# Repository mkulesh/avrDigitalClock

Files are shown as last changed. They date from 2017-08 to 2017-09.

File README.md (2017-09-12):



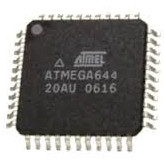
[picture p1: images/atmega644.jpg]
#  "A digital clock based on ATmega644 MCU"

This repository provides hardware layout and firmware for a digital clock based on ATmega644 MCU
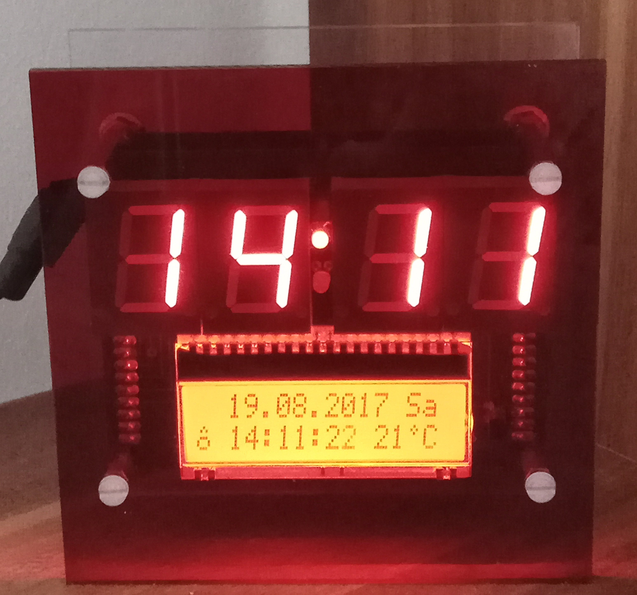
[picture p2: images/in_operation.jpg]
In operation


## Hardware design
This clock consist of two boards:
- the first display board contains four 0.8 inch. single digit numerical displays and one 2x16 chars LCD-display.
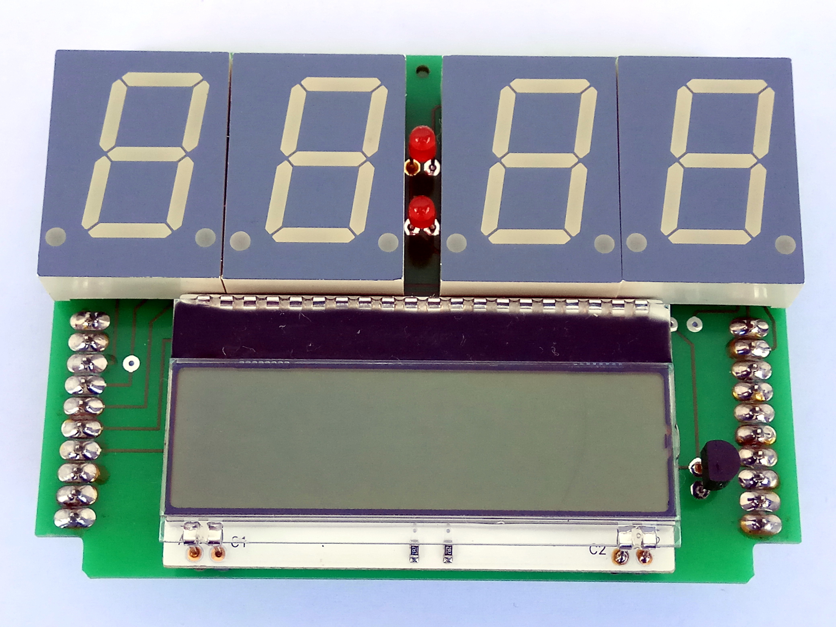
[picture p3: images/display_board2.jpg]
Display board


- the second board contains ATmega644 MCU with necessary periphery: voltage regulator, light sensor, temperature sensor, buttons, programming connector, 32.7680kHz crystal, DCF77 receiver with ferrite core.
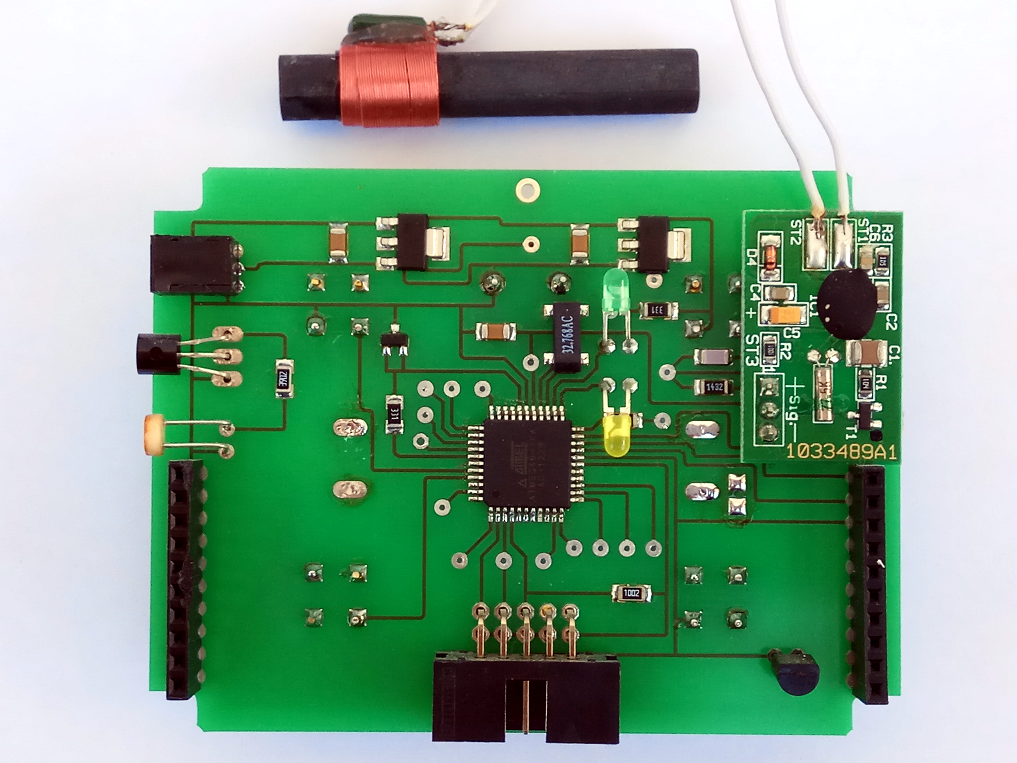
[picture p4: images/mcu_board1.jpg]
Mcu board


PCB are developed in Eagle CAD (see directory pcb):
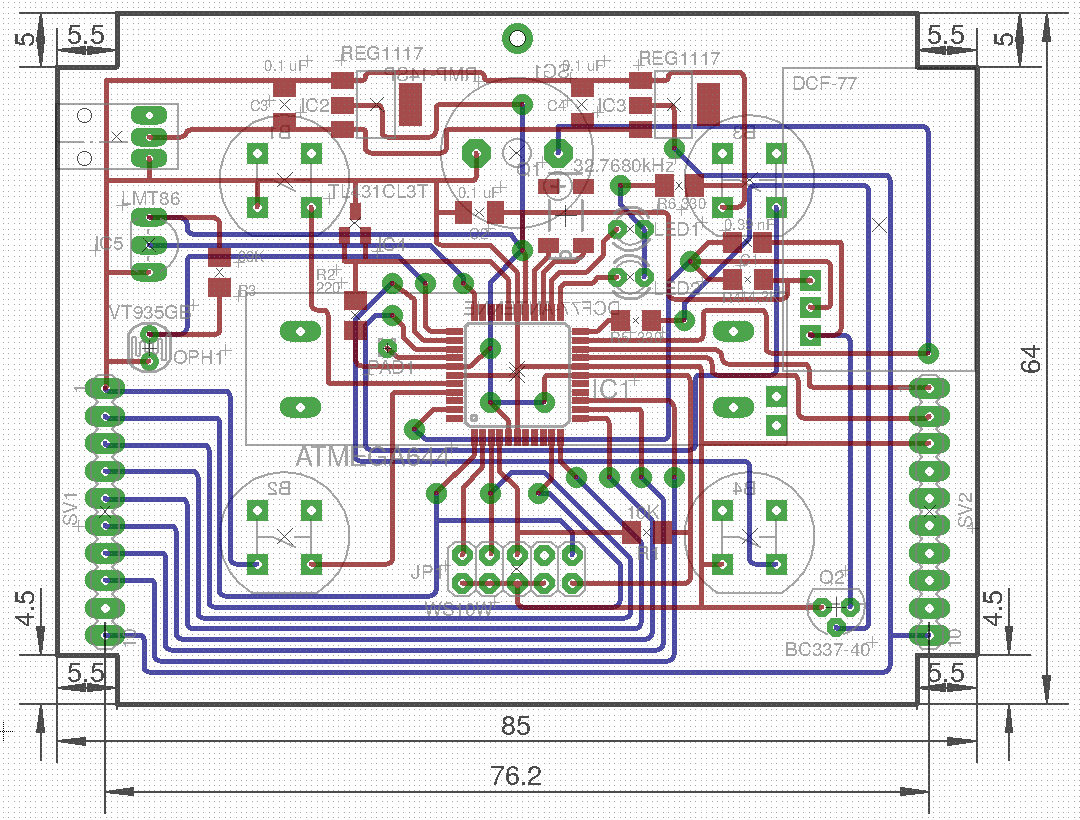
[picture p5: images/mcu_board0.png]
Mcu board layout

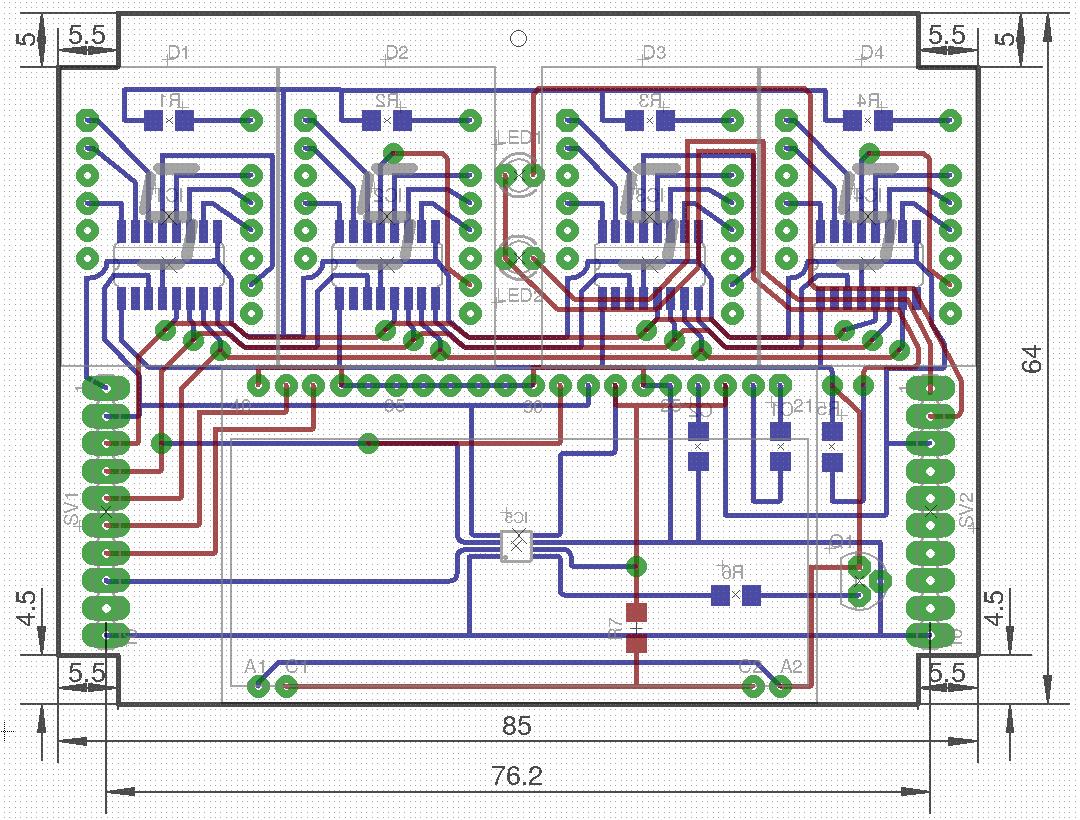
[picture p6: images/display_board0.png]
Display board layout


## Firmware
The firmware is written in C++ in Atmel Studio 6.0 (see directory src). The main idea here is to collect low-level routines in an object-oriented library and develop the main logic of the application using objects that implements different hardware elements.

## List of components
- DC connector: 1x DC-8N
- voltage regulators: 2x LD1117S33CTR
- temperature sensor: 1x LMT86LP
- voltage reference: 1x TL431CL3T
- 32.7680kHz crystal: 1x EuroQuartz PH32768X
- DCF77 receiver: 1x ELV Elektronik DCF-2 with ferrite core
- LED 3mm: 4x
- light sensor: 1v VT935G-B
- MCU ATMEGA644PA-AU TQFP-44
- transistors: 1xBC337-40, 1x J105
- piezo buzzer: 1x RMP-14SP
- buttons: 4x D6X
- shift register: 4x SN74HC595DR
- digital/analog converter: 1x MCP4901
- 7-segment display: 4x SC08-11SRWA
- LCD-display: 1x DOG-M162 with back-light (i.e EA LED55X31-R)

## There are some known problems in this project
- DCF-2 works really bad (instable signal): ether ferrite core or software problem
- Resting in Eagle design rules is invalid
- Wrong position of the DC connector: it shall be placed on bottom instaead of top of board
- voltage of 7-segment display and LCD back-light is regulated using MCP4901 and J105: regulation interal is too short

## License

This software is published under the *GNU General Public License, Version 3*

Copyright (C) 2014-2017 Mikhail Kulesh

This program is free software: you can redistribute it and/or modify it under the terms of the GNU General Public License as published by the Free Software Foundation, either version 3 of the License, or (at your option) any later version.

This program is distributed in the hope that it will be useful, but WITHOUT ANY WARRANTY; without even the implied warranty of MERCHANTABILITY or FITNESS FOR A PARTICULAR PURPOSE.  See the GNU General Public License for more details. You should have received a copy of the GNU General Public License along with this program.

If not, see [www.gnu.org/licenses](http://www.gnu.org/licenses).

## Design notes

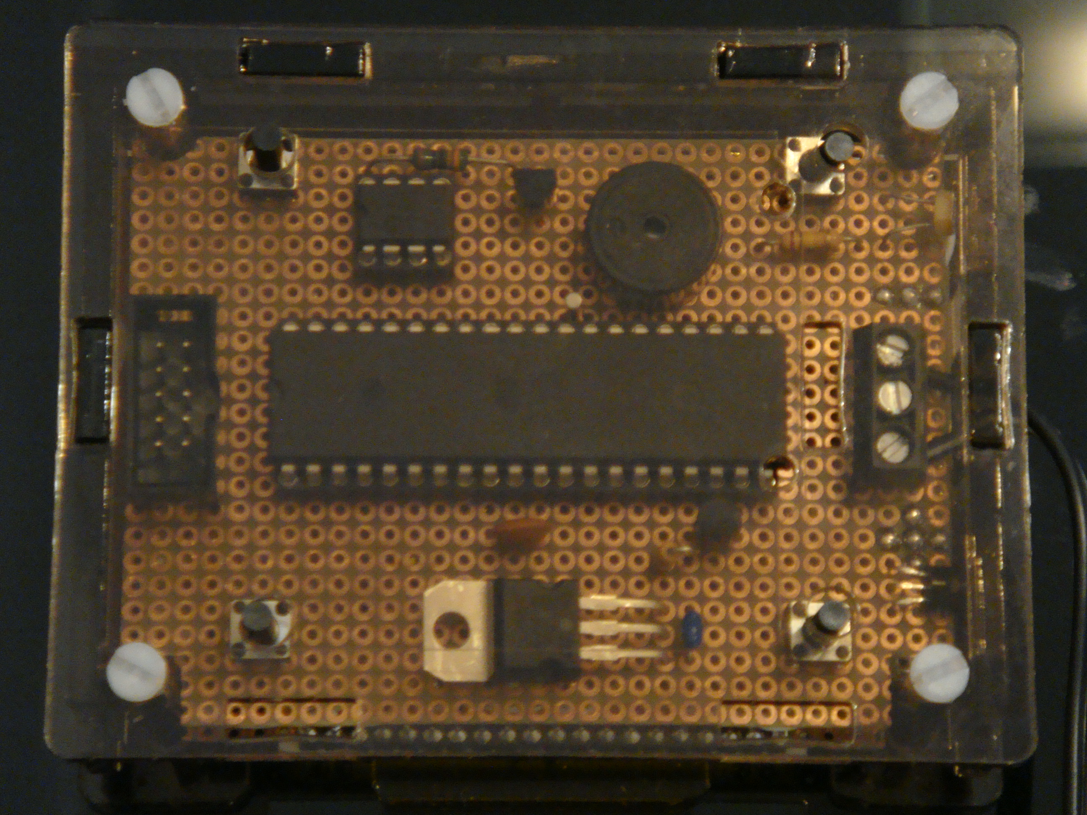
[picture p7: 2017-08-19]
images/prototype1.jpg

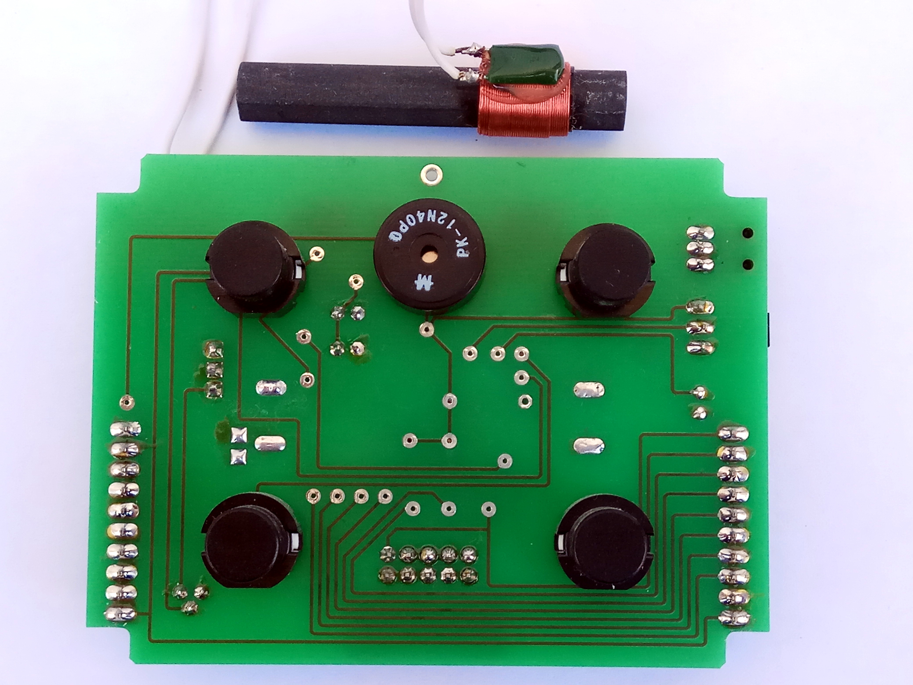
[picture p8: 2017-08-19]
images/mcu_board2.jpg

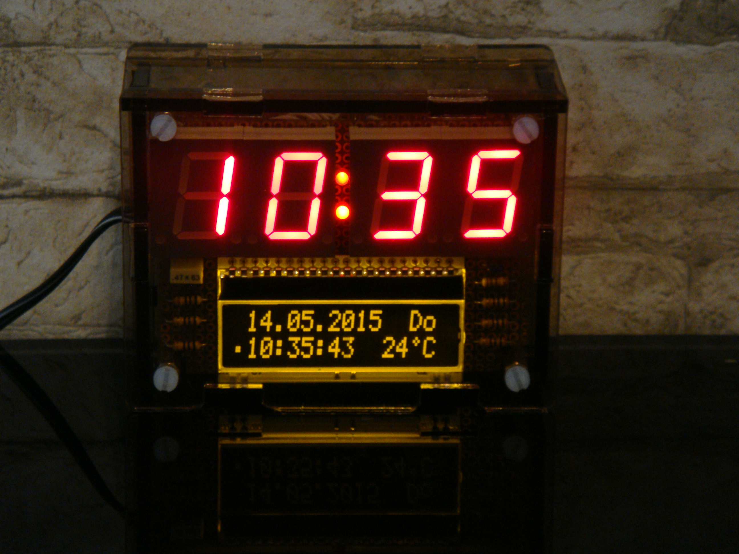
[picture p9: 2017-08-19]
images/prototype2.jpg

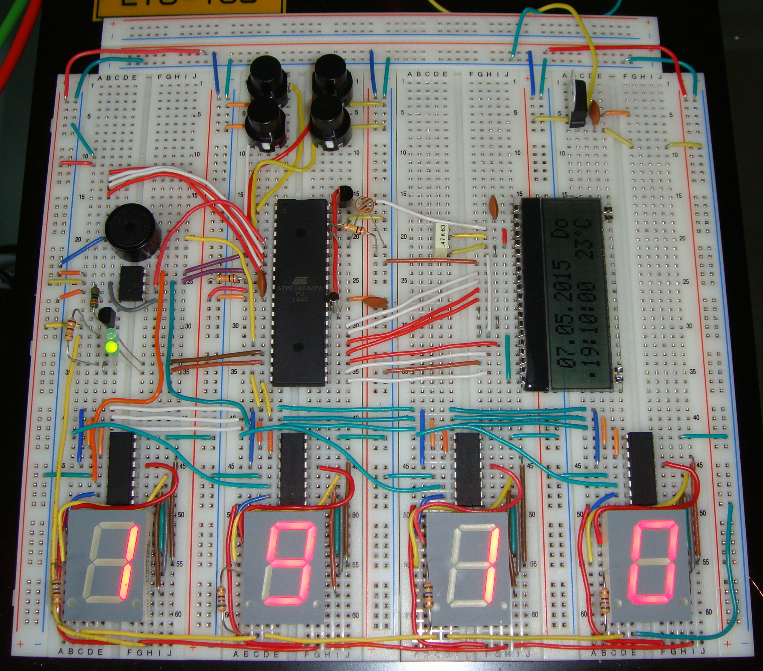
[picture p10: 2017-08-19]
images/on_breadboard1.jpg

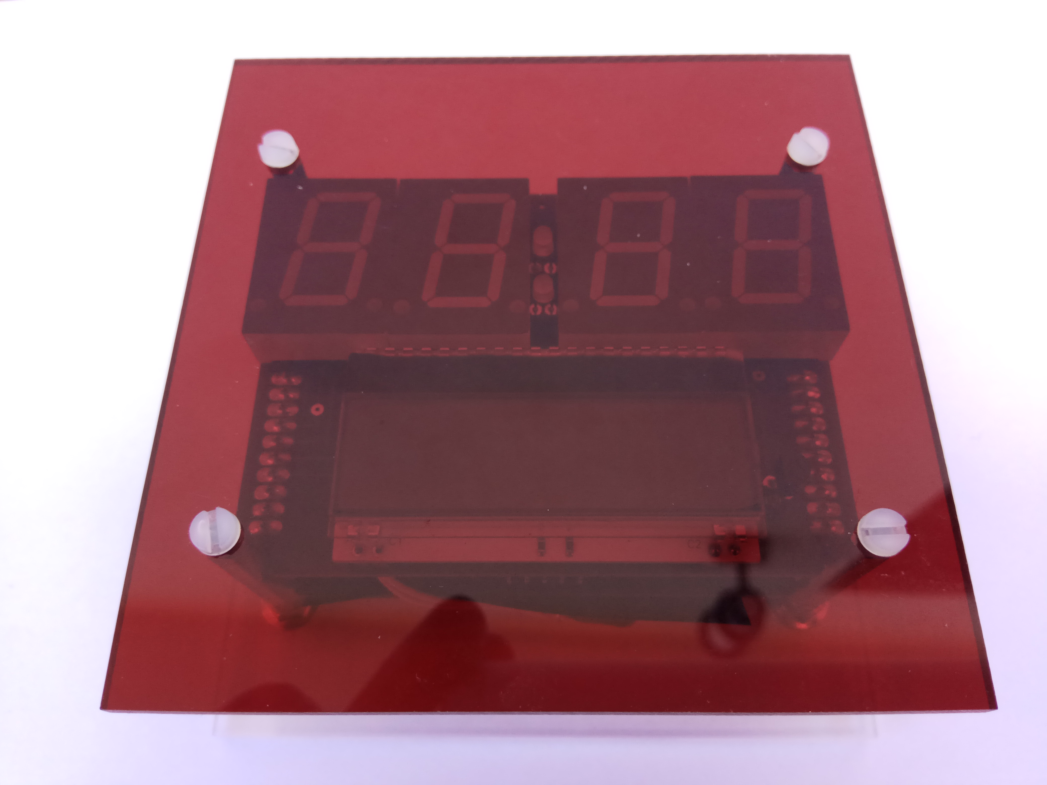
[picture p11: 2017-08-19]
images/top_view.jpg

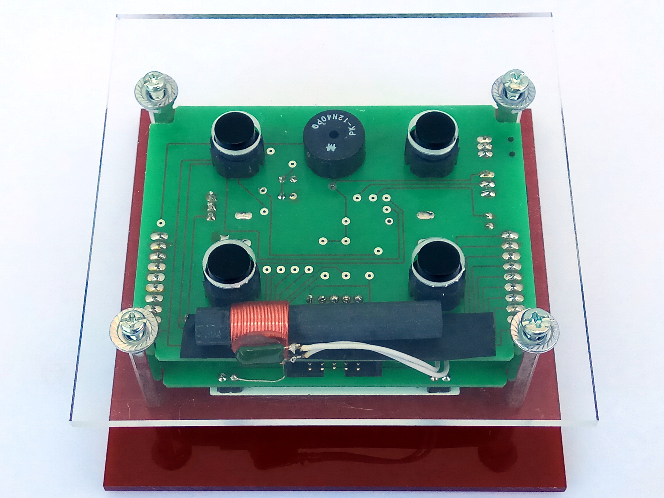
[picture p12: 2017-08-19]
images/bottom_view.jpg

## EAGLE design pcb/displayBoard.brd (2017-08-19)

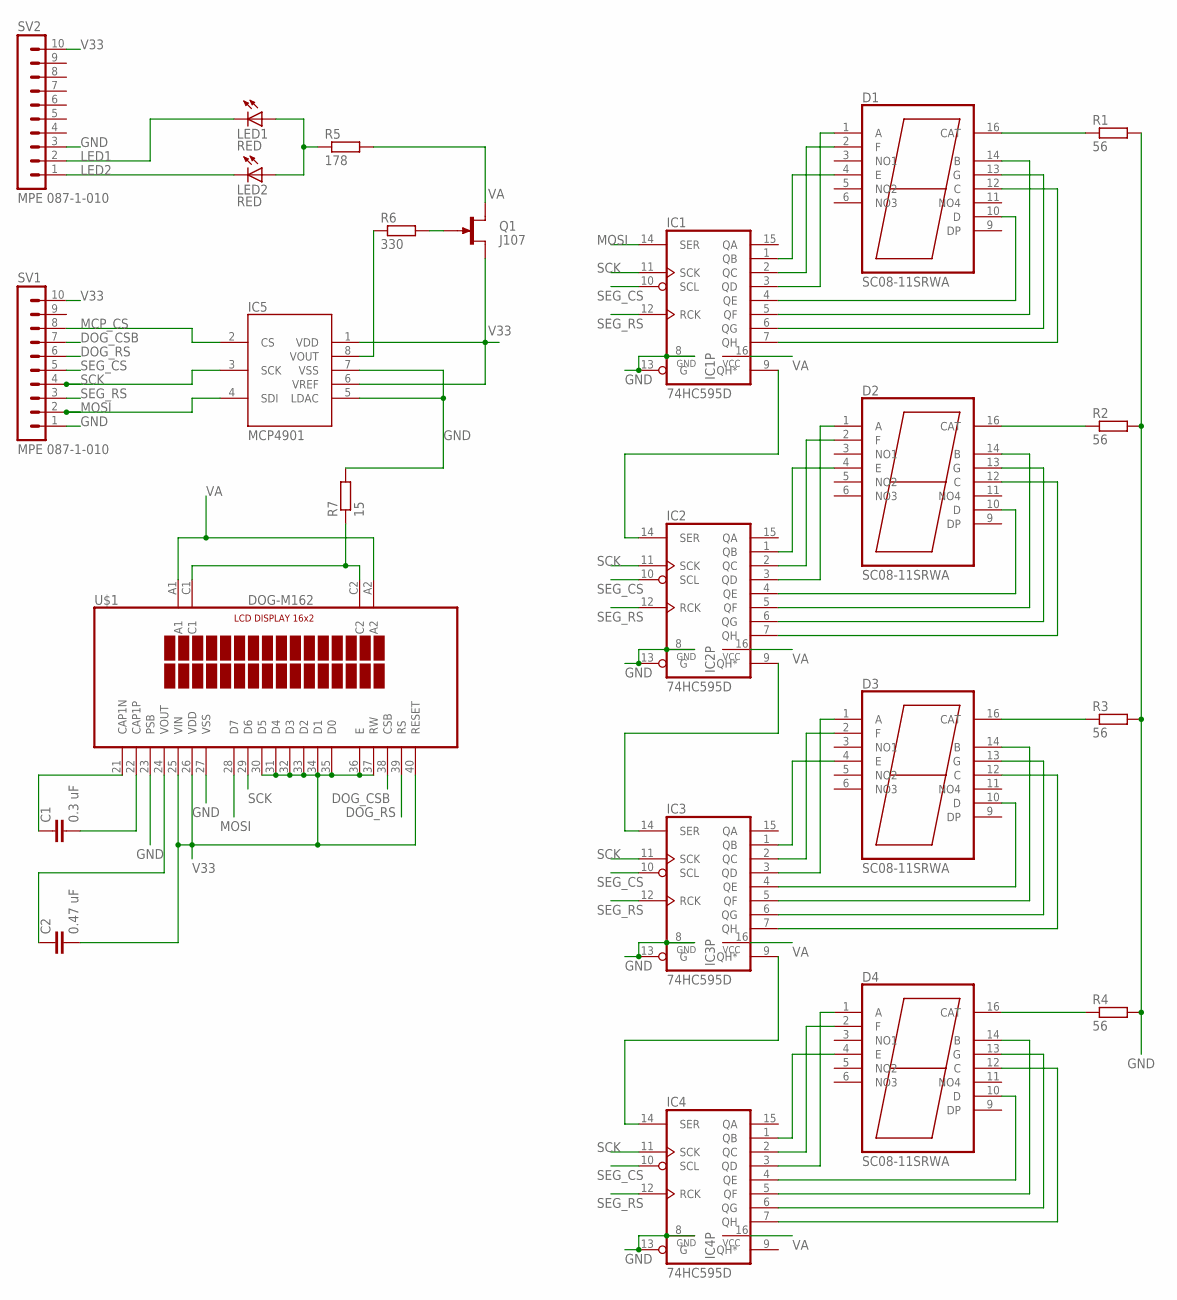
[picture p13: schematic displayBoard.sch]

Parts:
C1: 0.3 uF; C1206
C2: 0.47 uF; C1206
D1, D2, D3, D4: SC08-11SRWA
IC1, IC2, IC3, IC4: 74HC595D; SO16
IC5: MCP4901; MSOP8
LED1, LED2: RED; LED3MM
Q1: J107; TO92R
R1, R2, R3, R4: 56; R1206
R5: 178; R1206
R6: 330; R1206
R7: 15; R1206
SV1, SV2: MPE 087-1-010; MA10-1
U$1: DOG-M162; DOGM162

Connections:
DOG_CSB: SV1.7, U$1.38 (CSB)
DOG_RS: SV1.6, U$1.39 (RS)
GND: IC1.8 (GND), IC1.13 (G), IC2.8 (GND), IC2.13 (G), IC3.8 (GND), IC3.13 (G), IC4.8 (GND), IC4.13 (G), IC5.5 (LDAC), IC5.7 (VSS), R1.2, R2.2, R3.2, R4.2, R7.2, SV1.1, SV2.3, U$1.23 (PSB), U$1.27 (VSS)
LED1: LED1.K (C), SV2.2
LED2: LED2.K (C), SV2.1
MCP_CS: IC5.2 (CS), SV1.8
MOSI: IC1.14 (SER), IC5.4 (SDI), SV1.2, U$1.28 (D7)
unnamed: D1.4 (E), IC1.1 (QB)
unnamed: D1.2 (F), IC1.2 (QC)
unnamed: D1.1 (A), IC1.3 (QD)
unnamed: D1.10 (D), IC1.4 (QE)
unnamed: D1.14 (B), IC1.5 (QF)
unnamed: D1.13 (G), IC1.6 (QG)
unnamed: D1.12 (C), IC1.7 (QH)
unnamed: D2.4 (E), IC2.1 (QB)
unnamed: D2.2 (F), IC2.2 (QC)
unnamed: D2.1 (A), IC2.3 (QD)
unnamed: D2.10 (D), IC2.4 (QE)
unnamed: D2.14 (B), IC2.5 (QF)
unnamed: D2.13 (G), IC2.6 (QG)
unnamed: D2.12 (C), IC2.7 (QH)
unnamed: IC1.9 (QH*), IC2.14 (SER)
unnamed: D3.4 (E), IC3.1 (QB)
unnamed: D3.2 (F), IC3.2 (QC)
unnamed: D3.1 (A), IC3.3 (QD)
unnamed: D3.10 (D), IC3.4 (QE)
unnamed: D3.14 (B), IC3.5 (QF)
unnamed: D3.13 (G), IC3.6 (QG)
unnamed: D3.12 (C), IC3.7 (QH)
unnamed: D4.4 (E), IC4.1 (QB)
unnamed: D4.2 (F), IC4.2 (QC)
unnamed: D4.1 (A), IC4.3 (QD)
unnamed: D4.10 (D), IC4.4 (QE)
unnamed: D4.14 (B), IC4.5 (QF)
unnamed: D4.13 (G), IC4.6 (QG)
unnamed: D4.12 (C), IC4.7 (QH)
unnamed: IC3.9 (QH*), IC4.14 (SER)
unnamed: IC2.9 (QH*), IC3.14 (SER)
unnamed: D1.16 (CAT), R1.1
unnamed: D2.16 (CAT), R2.1
unnamed: D3.16 (CAT), R3.1
unnamed: D4.16 (CAT), R4.1
unnamed: LED1.A, LED2.A, R5.1
unnamed: C1.1, U$1.21 (CAP1N)
unnamed: C1.2, U$1.22 (CAP1P)
unnamed: C2.1, U$1.24 (VOUT)
unnamed: IC5.8 (VOUT), R6.1
unnamed: Q1.G, R6.2
unnamed: R7.1, U$1.C1, U$1.C2
SCK: IC1.11 (SCK), IC2.11 (SCK), IC3.11 (SCK), IC4.11 (SCK), IC5.3 (SCK), SV1.4, U$1.29 (D6)
SEG_CS: IC1.10 (SCL), IC2.10 (SCL), IC3.10 (SCL), IC4.10 (SCL), SV1.5
SEG_RS: IC1.12 (RCK), IC2.12 (RCK), IC3.12 (RCK), IC4.12 (RCK), SV1.3
V33: C2.2, IC5.1 (VDD), IC5.6 (VREF), Q1.S, SV1.10, SV2.10, U$1.25 (VIN), U$1.26 (VDD), U$1.30 (D5), U$1.31 (D4), U$1.32 (D3), U$1.33 (D2), U$1.34 (D1), U$1.35 (D0), U$1.36 (E), U$1.37 (RW), U$1.40 (RESET)
VA: IC1.16 (VCC), IC2.16 (VCC), IC3.16 (VCC), IC4.16 (VCC), Q1.D, R5.2, U$1.A1, U$1.A2

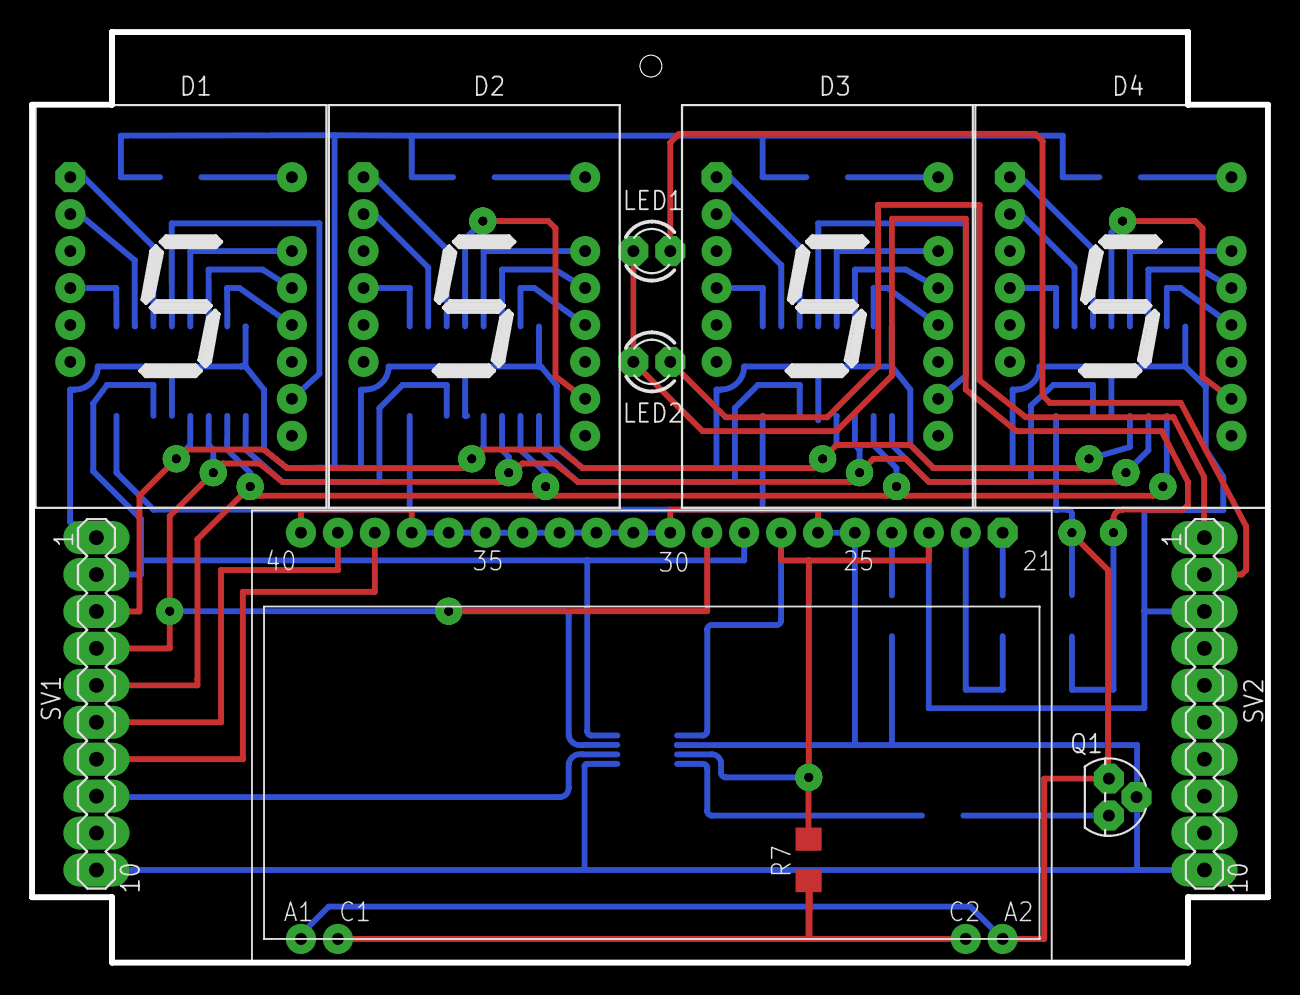
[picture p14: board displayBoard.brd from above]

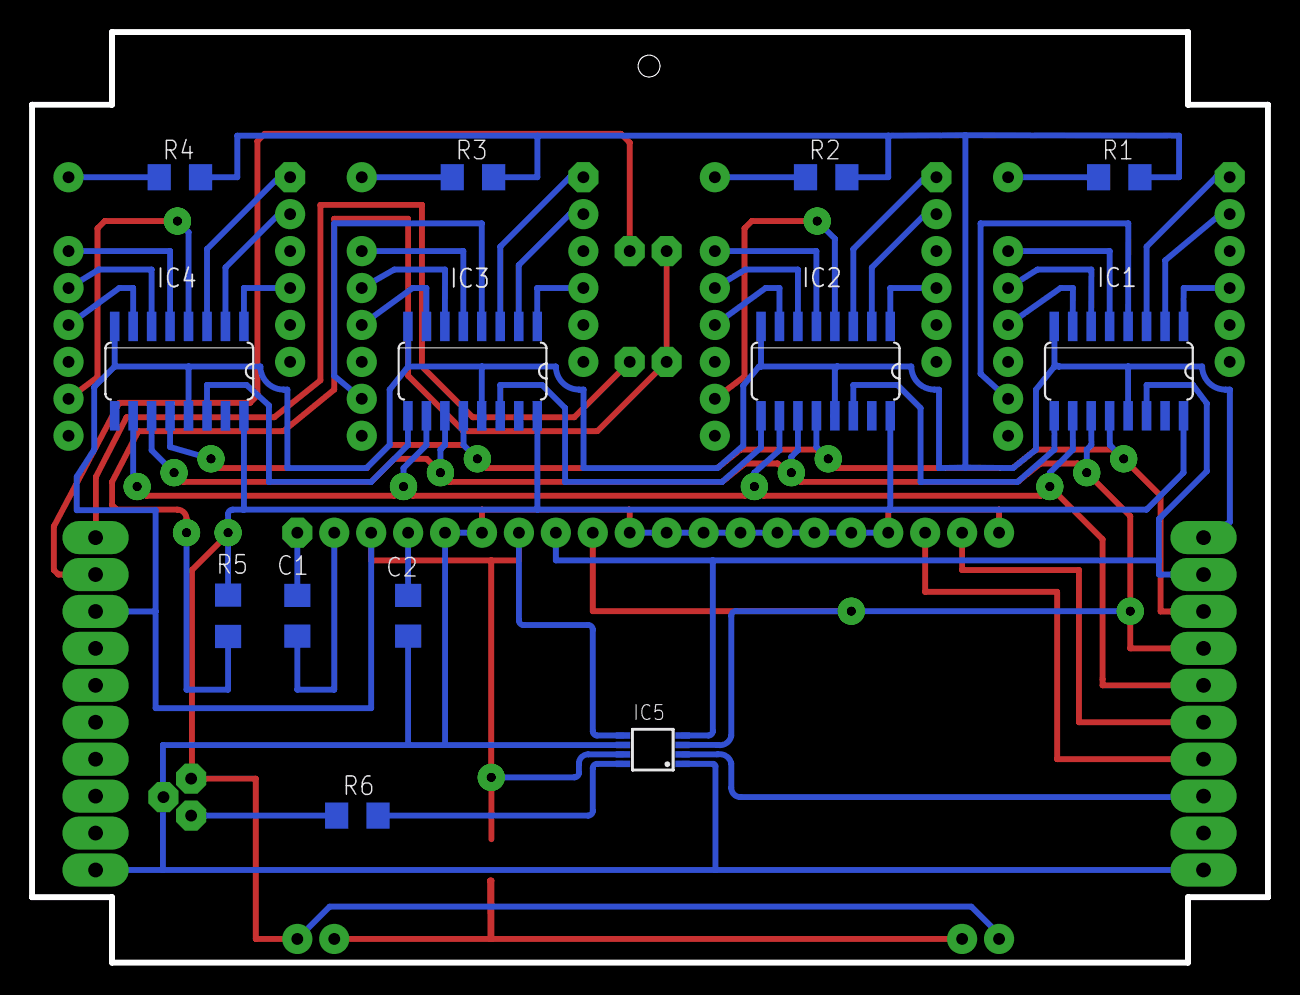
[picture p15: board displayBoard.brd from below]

Board: 2 copper layers, 85.0 x 64.0 mm, 24 parts (13 on the bottom side), 54 nets.

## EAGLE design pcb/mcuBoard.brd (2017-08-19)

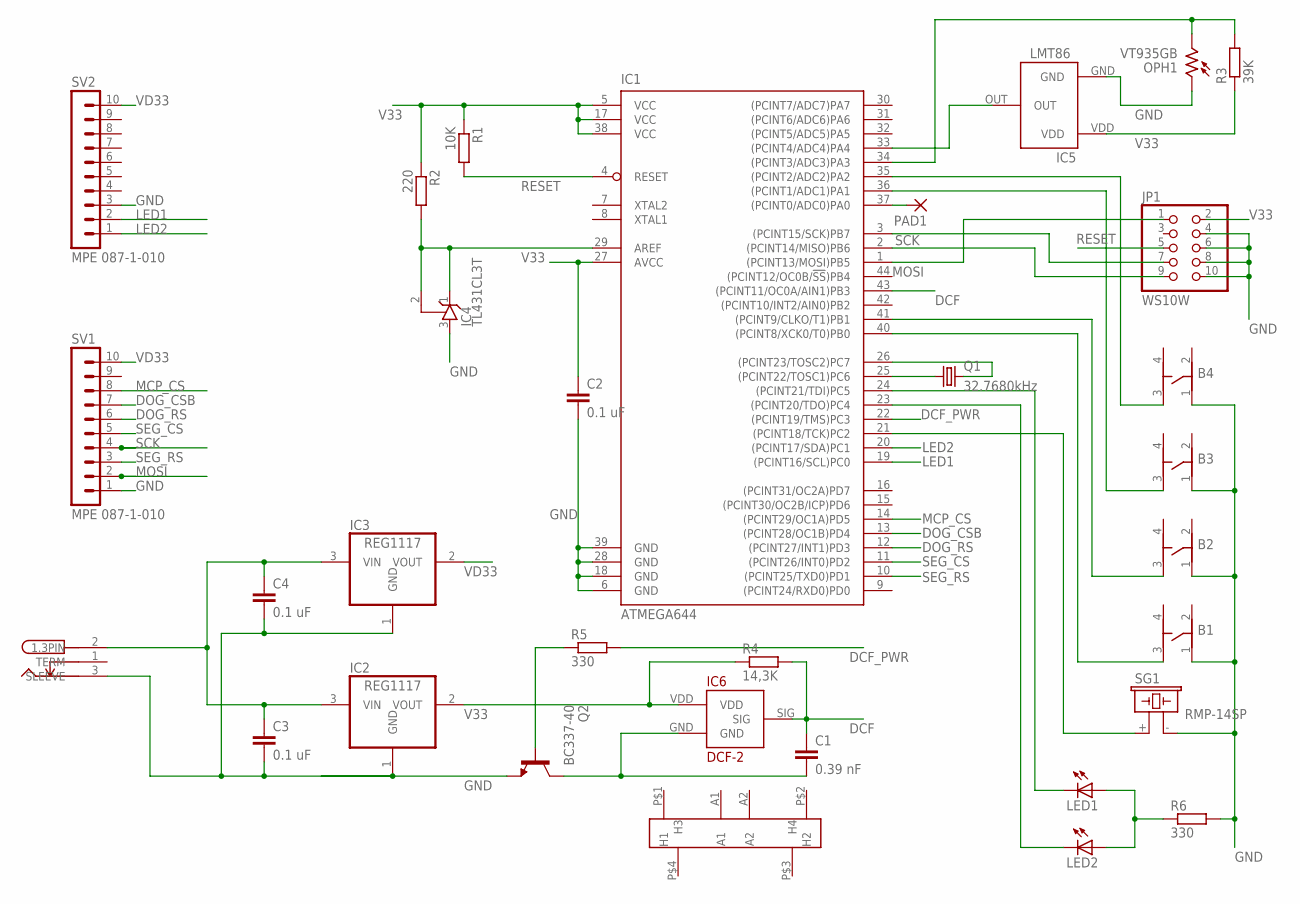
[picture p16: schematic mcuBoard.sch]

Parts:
B1, B2, B3, B4: BUTTON-D6X
C1: 0.39 nF; C1206
C2, C3, C4: 0.1 uF; C1206K
IC1: ATMEGA644; TQFP44
IC2, IC3: REG1117; SOT223
IC4: TL431CL3T; SOT23
IC5: LMT86
IC6: DCF77
JP1: WS10W; 2X05
LED1, LED2: LED3MM
OPH1: VT935GB; VT900
PAD1: 1,6/0,8
Q1: 32.7680kHz; MC-306
Q2: BC337-40; TO92
R1: 10K; M1206
R2: 220; M1206
R3: 39K; M1206
R4: 14,3K; R1206
R5: 330; R1206
R6: 330; M1206
SG1: RMP-14SP; F/CM12P
SV1, SV2: MPE 087-1-010; MA10-1
U$1: DC-8N; BUCHSE-1.3X3.75
U$2: DCF77-ANT

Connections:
DCF: C1.1, IC1.43 ((PCINT11/OC0A/AIN1)PB3), IC6.SIG, R4.2
DCF_PWR: IC1.22 ((PCINT19/TMS)PC3), R5.2
DOG_CSB: IC1.13 ((PCINT28/OC1B)PD4), SV1.7
DOG_RS: IC1.12 ((PCINT27/INT1)PD3), SV1.6
GND: B1.1, B2.1, B3.1, B4.1, C2.2, C3.2, C4.2, IC1.6 (GND), IC1.18 (GND), IC1.28 (GND), IC1.39 (GND), IC2.1 (GND), IC3.1 (GND), IC4.3 (A), IC5.GND, JP1.4, JP1.6, JP1.8, JP1.10, OPH1.1, Q2.1 (E), R6.2, SG1.- (2), SV1.1, SV2.3, U$1.3 (SLEEVE)
LED1: IC1.19 ((PCINT16/SCL)PC0), SV2.2
LED2: IC1.20 ((PCINT17/SDA)PC1), SV2.1
MCP_CS: IC1.14 ((PCINT29/OC1A)PD5), SV1.8
MOSI: IC1.1 ((PCINT13/MOSI)PB5), JP1.1, SV1.2
unnamed: C3.1, C4.1, IC2.3 (VIN), IC3.3 (VIN), U$1.2 (1.3PIN)
unnamed: IC1.2 ((PCINT14/MISO)PB6), JP1.9
unnamed: B3.3, IC1.36 ((PCINT1/ADC1)PA1)
unnamed: B2.3, IC1.41 ((PCINT9/CLKO/T1)PB1)
unnamed: B1.3, IC1.40 ((PCINT8/XCK0/T0)PB0)
unnamed: IC1.25 ((PCINT22/TOSC1)PC6), Q1.1
unnamed: IC1.29 (AREF), IC4.1 (C), IC4.2 (R), R2.2
unnamed: IC1.26 ((PCINT23/TOSC2)PC7), Q1.4 (2)
unnamed: IC1.21 ((PCINT18/TCK)PC2), SG1.+ (1)
unnamed: IC1.33 ((PCINT4/ADC4)PA4), IC5.OUT
unnamed: B4.3, IC1.35 ((PCINT2/ADC2)PA2)
unnamed: IC1.34 ((PCINT3/ADC3)PA3), OPH1.2, R3.2
unnamed: IC1.37 ((PCINT0/ADC0)PA0), PAD1.1
unnamed: C1.2, IC6.GND, Q2.3 (C)
unnamed: Q2.2 (B), R5.1
unnamed: LED1.A, LED2.A, R6.1
unnamed: IC1.24 ((PCINT21/TDI)PC5), LED1.K (C)
unnamed: IC1.23 ((PCINT20/TDO)PC4), LED2.K (C)
RESET: IC1.4 (RESET), JP1.5, R1.2
SCK: IC1.3 ((PCINT15/SCK)PB7), JP1.7, SV1.4
SEG_CS: IC1.11 ((PCINT26/INT0)PD2), SV1.5
SEG_RS: IC1.10 ((PCINT25/TXD0)PD1), SV1.3
V33: C2.1, IC1.5 (VCC), IC1.17 (VCC), IC1.27 (AVCC), IC1.38 (VCC), IC2.2 (VOUT), IC5.VDD, IC6.VDD, JP1.2, R1.1, R2.1, R3.1, R4.1
VD33: IC3.2 (VOUT), SV1.10, SV2.10

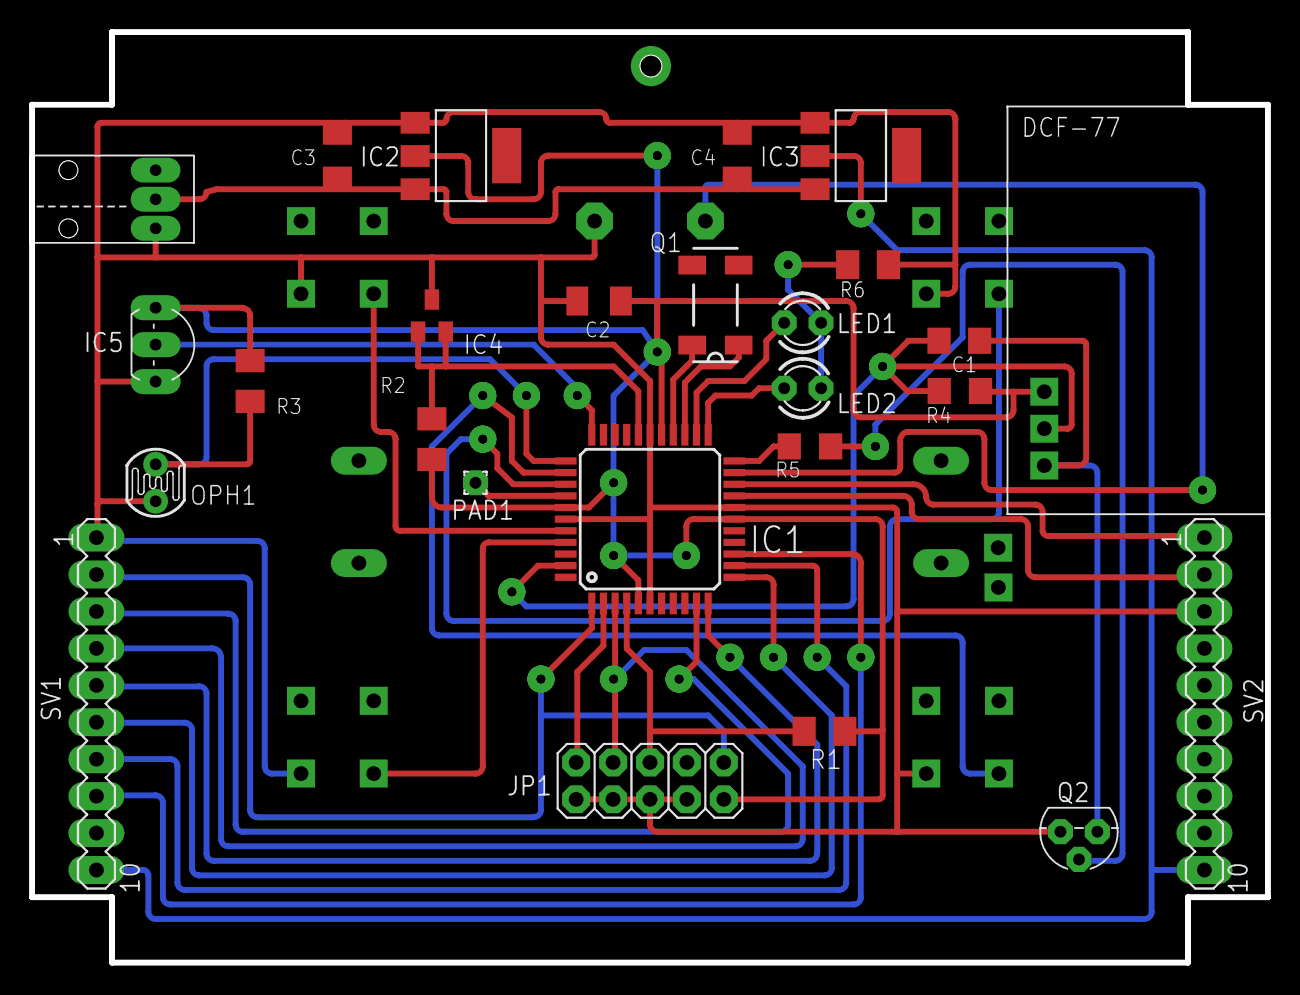
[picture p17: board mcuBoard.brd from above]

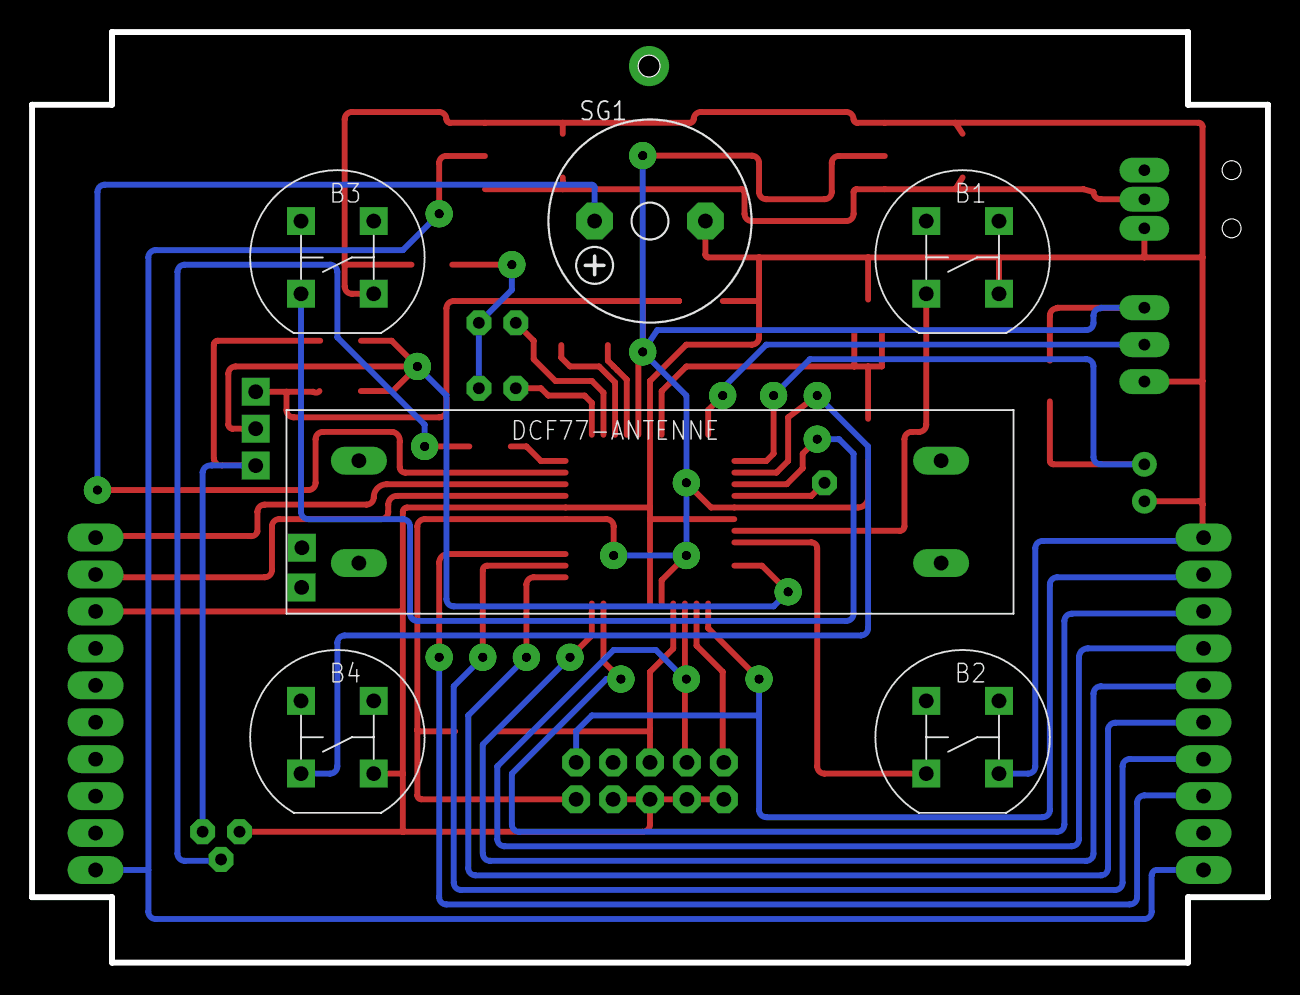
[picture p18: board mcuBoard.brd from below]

Board: 2 copper layers, 85.0 x 64.0 mm, 32 parts (6 on the bottom side), 33 nets.

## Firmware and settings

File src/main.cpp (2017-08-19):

/*******************************************************************************
 * avrDigitalClock - a digital clock based on ATmega644 MCU
 * *****************************************************************************
 * Copyright (C) 2014-2017 Mikhail Kulesh
 * 
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
 * You should have received a copy of the GNU General Public License
 * along with this program.  If not, see <http://www.gnu.org/licenses/>.
 ******************************************************************************/

#include "DigitalClock.h"
#include <avr/interrupt.h>
#include <avr/cpufunc.h>

// Real time machine
RealTimeClock rtc;
DigitalClock * clockPtr;

int main(void)
{
    System::disableJTAG();
    System::setClockDivisionFactor(System::PRE_1);
    System::setVoltage(3.32);

    DigitalClock dc(&rtc);
    clockPtr = &dc;
    dc.init();
    rtc.startClock();

    do
    {
        dc.periodic();
    }
    while (1);
    return 0;
}

// overflow interrupt
ISR(TIMER2_OVF_vect)
{
    rtc.onInterrupOverflow();
}

// compare output interrupt
ISR(TIMER1_COMPA_vect)
{
    rtc.onInterrupCompareMatch();
}

// analog comparator interrupt
ISR(ANALOG_COMP_vect)
{
    clockPtr->onComparatorInterrupt();
}

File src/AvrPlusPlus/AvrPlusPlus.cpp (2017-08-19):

/*******************************************************************************
 * avrDigitalClock - a digital clock based on ATmega644 MCU
 * *****************************************************************************
 * Copyright (C) 2014-2017 Mikhail Kulesh
 * 
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
 * You should have received a copy of the GNU General Public License
 * along with this program.  If not, see <http://www.gnu.org/licenses/>.
 ******************************************************************************/

#include "AvrPlusPlus.h"

#include <stdlib.h>
#include <avr/interrupt.h>

/************************************************************************
 * Common methods
 ************************************************************************/
void __cxa_pure_virtual(void)
{
    // We might want to write some diagnostics to uart in this case
    exit(0);
}

void __cxa_deleted_virtual(void)
{
    // We might want to write some diagnostics to uart in this case
    exit(0);
}

namespace AvrPlusPlus
{

/************************************************************************
 * Class System
 ************************************************************************/
float System::voltage = 0.0;

void System::setClockDivisionFactor(System::Prescale prescale)
{
    CLKPR = (1 << CLKPCE); // enable a change to CLKPR
    CLKPR = prescale; // set the necessary factor
}

void System::disableJTAG()
{
#ifdef JTD
    unsigned char tmp = (1 << JTD);
    MCUCR = tmp; // Disable JTAG
    MCUCR = tmp;// Disable JTAG
#endif
}

/************************************************************************
 * Class IOPort
 ************************************************************************/
IOPort::IOPort(Name name)
{
    bool initialized = false;
    switch (name)
    {
    case A:
#ifdef PORTA
        port = &PORTA; pins = &PINA; ddr = &DDRA; initialized = true;
#endif
        break;

    case B:
#ifdef PORTB
        port = &PORTB; pins = &PINB; ddr = &DDRB; initialized = true;
#endif
        break;

    case C:
#ifdef PORTC
        port = &PORTC; pins = &PINC; ddr = &DDRC; initialized = true;
#endif
        break;

    case D:
#ifdef PORTD
        port = &PORTD; pins = &PIND; ddr = &DDRD; initialized = true;
#endif
        break;
    }
    if (!initialized)
    {
        abort();
    }
}

void IOPort::setDirection(Direction direction)
{
    *ddr = (direction == INPUT) ? 0xFF : 0;
}

void IOPort::putChar(unsigned char value)
{
    *port = value;
}

/************************************************************************
 * Class IOPin
 ************************************************************************/
IOPin::IOPin(Name name, unsigned char pinNr, Direction direction) : IOPort(name)
{
    pin = pinNr;
    setDirection(direction);
}

void IOPin::setDirection(Direction direction)
{
    if (direction == INPUT)
    {
        *ddr &= ~(1 << pin);
    }
    else
    {
        *ddr |= (1 << pin);
    }
}

void IOPin::setHigh()
{
    *port |= (1 << pin);
}

void IOPin::setLow()
{
    *port &= ~(1 << pin);
}

void IOPin::putBit(bool value)
{
    if (value)
    {
        *port |= (1 << pin);
    }
    else
    {
        *port &= ~(1 << pin);
    }
}

bool IOPin::getBit() const
{
    return *port & (1 << pin);
}

bool IOPin::readInput() const
{
    return *pins & (1 << pin);
}

/************************************************************************
 * Class RealTimeClock
 ************************************************************************/
RealTimeClock::RealTimeClock() :
        syncMs1(0), syncMs2(0), errorMs(0), timeMillisec(0), timeSec(0)
{
    // empty
}

void RealTimeClock::setupTimer1()
{
    // 16-bit timer T1 is clocked from MCU generator. Comparator interrupts it every milliseconds.
    // Disable the Timer/Counter1 interrupts
    TIMSK1 = 0;
    // TCCR1A: Timer/Counter1 Control Register A:
    // Normal port operation, OCnA/OCnB disconnected: COM1A1/COM1B1 COM1A0/COM1B0 zero,
    // Timer/Counter Mode of Operation normal: WGM11, WGM10 zero
    TCCR1A = (0 << COM1A1) | (0 << COM1B1) | (0 << COM1A0) | (0 << COM1B0) | (0 << WGM11) | (0 << WGM10);
    // TCCR1B: Timer/Counter1 Control Register B:
    // Waveform Generation: WGM13 zero, WGM12 = 1: Clear Timer on Compare match (CTC)
    // Clock Select: clkI/O/1 (No prescaling): CS10 = 1;
    TCCR1B = (0 << WGM13) | (1 << WGM12) | (0 << CS12) | (0 << CS11) | (1 << CS10);
    // TCCR1C: Timer/Counter1 Control Register C:
    // No Force Output Compare:
    TCCR1C = (0 << FOC1A) | (0 << FOC1B);
    // Set initial value
    TCNT1 = 0;
    // Output Compare Register 1A: 1000 (1 ms) depending on current pre-scale
    switch (CLKPR | (0 << CLKPCE))
    {
    case System::PRE_1:
        OCR1A = F_CRYSTAL * 1000;
        break;
    case System::PRE_2:
        OCR1A = F_CRYSTAL * 500;
        break;
    case System::PRE_4:
        OCR1A = F_CRYSTAL * 250;
        break;
    case System::PRE_8:
        OCR1A = F_CRYSTAL * 125;
        break;
    }
    // Clear the Timer Interrupt Flags
    TIFR1 = (1 << OCF1A);
    // TIMSK1: Timer/Counter1 Interrupt Mask Register
    // Enable Output Compare A Match Interrupt: OCIE1A = 1
    TIMSK1 = (1 << OCIE1A);
}

void RealTimeClock::setupTimer2()
{
    // 8-bit timer T2 is used asynchronously from 32kHz quartz with overflow interrupt.
    // Disable the Timer/Counter2 interrupts
    TIMSK2 = 0;
    // Select clock source by setting AS2 as appropriate
    ASSR = (1 << AS2);
    // Set initial value
    TCNT2 = 0;
    // TCCR2B: Timer/Counter2 Control Register B:
    // Set prescaller 128: interrupt every second
    TCCR2B |= (1 << CS22) | (1 << CS20);
    // Wait for TCN2UB, OCR2xUB, and TCR2xUB
    while (ASSR & ((1 << TCN2UB) | (1 << TCR2BUB)));
    // Clear the Timer Interrupt Flags
    TIFR2 = (1 << TOV2);
    // Enable interrupts
    TIMSK2 = (1 << TOIE2);
}

void RealTimeClock::startClock()
{
    setupTimer1();
    setupTimer2();
    sei();
};

void RealTimeClock::onInterrupCompareMatch()
{
    if (syncMs1 < 999)
    {
        ++timeMillisec;
        ++syncMs1;
    }
    ++syncMs2;
}

void RealTimeClock::onInterrupOverflow()
{
    ++syncMs2;
    errorMs = syncMs2 - 1000;
    ++timeSec;
    timeMillisec = (time_ms) timeSec * 1000L;
    syncMs1 = syncMs2 = 0;
};

void RealTimeClock::setTime(time_t sec)
{
    cli();
    timeSec = sec;
    timeMillisec = (duration_ms) sec * 1000L;
    sei();
}

/************************************************************************
 * Class SpiDevice
 ************************************************************************/
SpiDevice::SpiDevice(Name spiPortName, unsigned char pinMosiNr, unsigned char pinSckNr, Name devicePortName, unsigned char pinCsNr) :
        IOPin(devicePortName, pinCsNr, OUTPUT),
        pinMosi(spiPortName, pinMosiNr, OUTPUT),
        pinSck(spiPortName, pinSckNr, OUTPUT)
{
    setHigh();
    SPCR |= (1 << SPE) | (1 << MSTR);
}
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

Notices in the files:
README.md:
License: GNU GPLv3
